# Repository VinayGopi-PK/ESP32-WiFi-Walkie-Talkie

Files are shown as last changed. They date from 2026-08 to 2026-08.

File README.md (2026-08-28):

# ESP32 Wi-Fi Walkie-Talkie

An **ESP32-based real-time Wi-Fi Walkie-Talkie** designed for voice communication using **UDP audio streaming**. The system uses an **INMP441 I2S digital microphone**, **MAX98357A I2S audio amplifier**, and a **Push-to-Talk (PTT)** control.

The hardware was designed in **KiCad**, including the schematic, PCB layout, and 3D visualization. The repository also contains the ESP32 Arduino source code and Gerber files for PCB manufacturing.

---

## Project Overview

This project is a wireless voice communication system based on two ESP32 boards communicating over Wi-Fi.

The voice signal is captured by the **INMP441 digital microphone** through the I2S interface. The ESP32 processes and transmits the audio data using **UDP over Wi-Fi**. At the receiving side, the audio is sent through I2S to the **MAX98357A audio amplifier**, which drives the speaker.

A **Push-to-Talk (PTT)** button is used to control voice transmission.

### Audio Communication Path

```text
Voice
  ↓
INMP441 I2S Microphone
  ↓
ESP32
  ↓
UDP Audio Streaming over Wi-Fi
  ↓
ESP32
  ↓
MAX98357A I2S Audio Amplifier
  ↓
Speaker
```

---

## Main Features

* ESP32-based wireless communication
* Real-time UDP audio streaming
* Wi-Fi-based voice communication
* I2S digital audio interface
* INMP441 I2S digital microphone
* MAX98357A I2S audio amplifier
* Push-to-Talk (PTT) control
* Custom PCB designed using KiCad
* Complete schematic design
* PCB layout design
* Front and back PCB layout
* 3D PCB visualization
* Gerber files for PCB manufacturing

---

## Hardware

| Component | Function |
| --- | --- |
| ESP32 | Main microcontroller and Wi-Fi communication |
| INMP441 | I2S digital microphone |
| MAX98357A | I2S audio amplifier |
| Push-to-Talk Button | Controls voice transmission |
| Speaker | Audio output |
| Custom PCB | Integrates the system hardware |

---

## Software

The ESP32 firmware was developed using **Arduino IDE**.

The repository contains the final Arduino source code used for the ESP32 Walkie-Talkie system.

### Communication

* Wireless technology: **Wi-Fi**
* Communication protocol: **UDP**
* Audio interface: **I2S**

---

## PCB Design

The custom PCB was designed using **KiCad**.

The PCB design includes:

* Complete schematic
* Component placement
* PCB routing
* Front copper layout
* Back copper layout
* Power and signal routing
* 3D PCB visualization
* Gerber manufacturing files

---

## PCB Design Preview

### Schematic

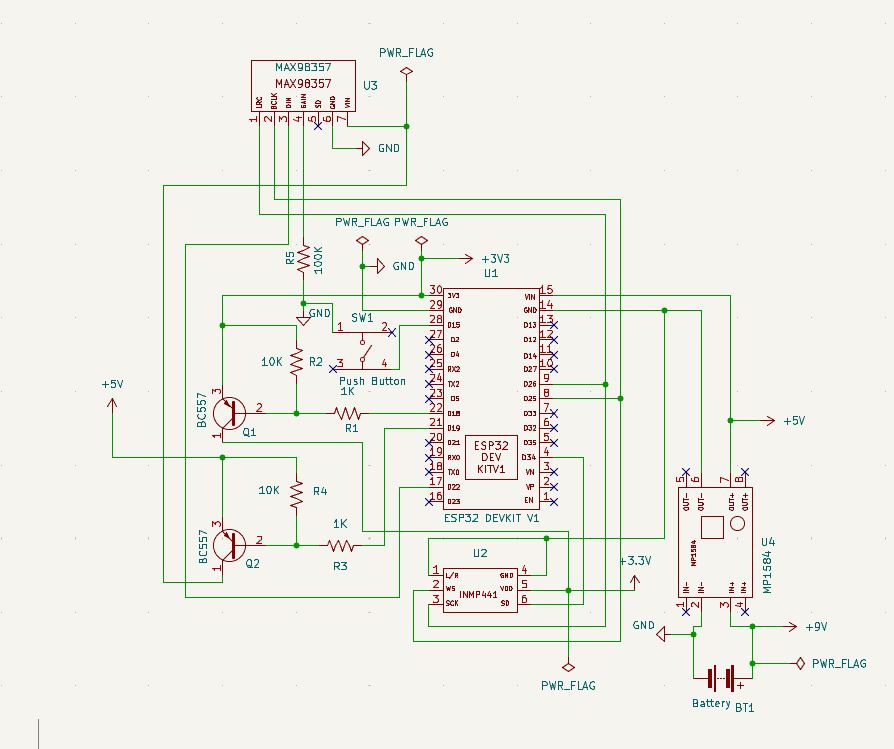
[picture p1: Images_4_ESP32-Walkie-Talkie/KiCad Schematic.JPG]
ESP32 Wi-Fi Walkie-Talkie Schematic


### PCB Front Layout

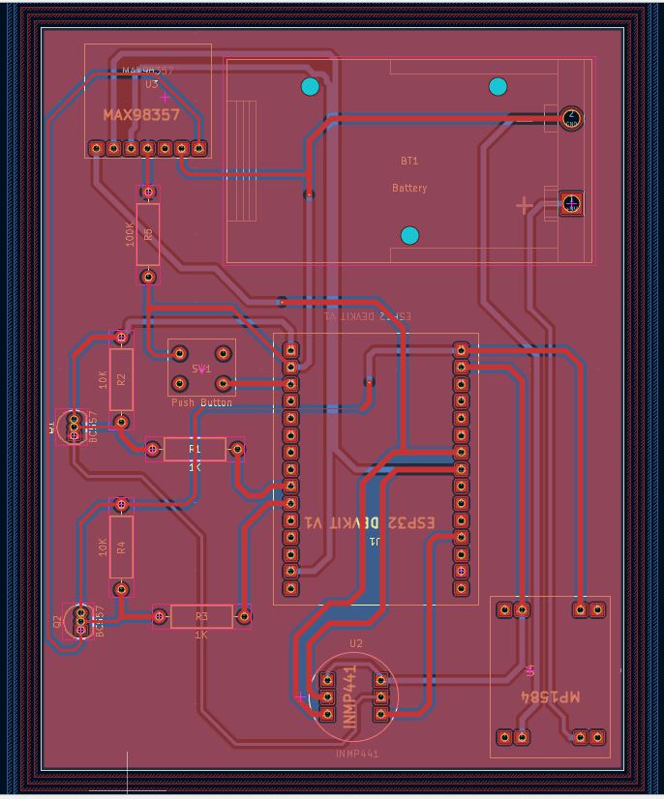
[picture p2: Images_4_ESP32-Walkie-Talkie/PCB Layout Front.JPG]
PCB Front Layout


### PCB Back Layout

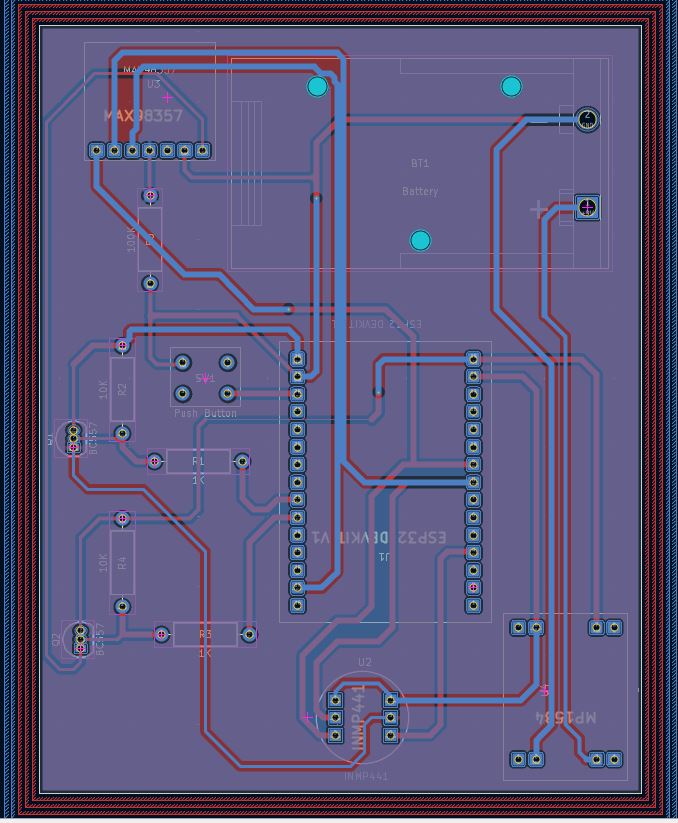
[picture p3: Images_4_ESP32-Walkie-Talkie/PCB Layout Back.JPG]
PCB Back Layout


### 3D View

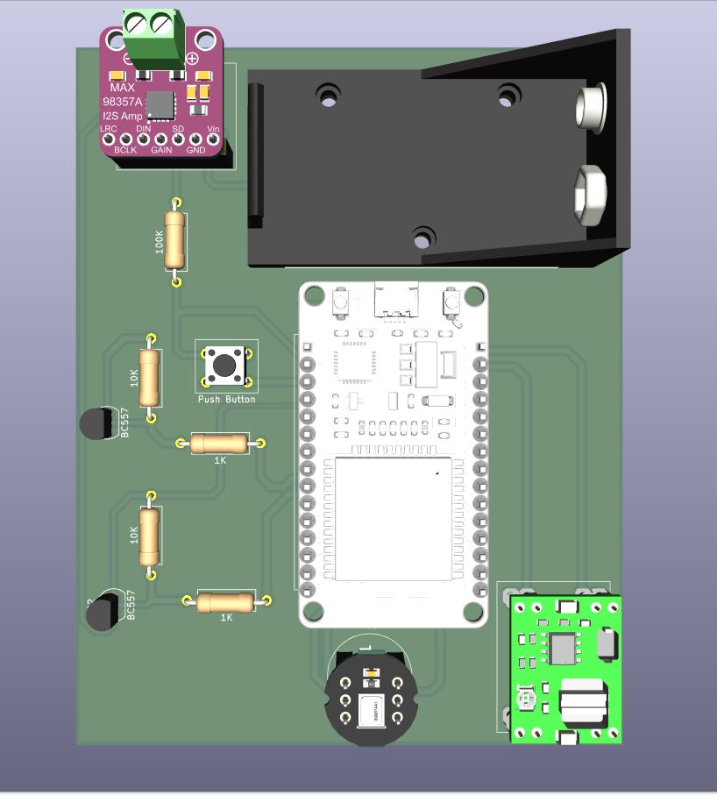
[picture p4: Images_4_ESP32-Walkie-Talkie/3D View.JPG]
PCB 3D View


---

## Repository Contents

### KiCad Design Files

The `ESP32_Walkie-Talkie Files` folder contains the KiCad project files, including:

* KiCad project file
* KiCad schematic
* KiCad PCB layout
* Component/project data files

### Arduino Source Code

The `Final_Codes` folder contains the final ESP32 Arduino source code for the Walkie-Talkie system.

### Gerber Files

The `Gerber Files_4_ESP32 Walkie-Talkie` folder contains the generated Gerber files required for PCB manufacturing.

### Project Images

The `Images_4_ESP32-Walkie-Talkie` folder contains:

* Schematic image
* PCB front layout
* PCB back layout
* PCB 3D view

---

## Design Tools

* **KiCad** — Schematic and PCB design
* **Arduino IDE** — ESP32 firmware development

---

## Technical Highlights

**Microcontroller:** ESP32
**Wireless Communication:** Wi-Fi
**Communication Protocol:** UDP
**Audio Interface:** I2S
**Digital Microphone:** INMP441
**Audio Amplifier:** MAX98357A
**Control:** Push-to-Talk (PTT)

---

## Project Objective

The objective of this project was to develop an **ESP32-based wireless voice communication system** while combining embedded programming, Wi-Fi networking, real-time UDP audio streaming, digital I2S audio, schematic design, PCB layout, and PCB manufacturing file generation.

---

## Project Type

**ESP32 Embedded System | Wi-Fi Communication | Digital Audio | PCB Design**

**Design Software:** KiCad
**Programming Environment:** Arduino IDE

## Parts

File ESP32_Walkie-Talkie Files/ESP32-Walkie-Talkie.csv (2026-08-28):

Reference | Qty | Value | DNP | Exclude from BOM | Exclude from Board | Footprint | Datasheet
BT1 | 1 | Battery |  |  |  | Battery:BatteryHolder_Eagle_12BH611-GR
Q1,Q2 | 2 | BC557 |  |  |  | Package_TO_SOT_THT:TO-92_Inline | https://www.onsemi.com/pub/Collateral/BC556BTA-D.pdf
R1,R3 | 2 | 1K |  |  |  | Resistor_THT:R_Axial_DIN0309_L9.0mm_D3.2mm_P12.70mm_Horizontal
R2,R4 | 2 | 10K |  |  |  | Resistor_THT:R_Axial_DIN0309_L9.0mm_D3.2mm_P12.70mm_Horizontal
R5 | 1 | 100K |  |  |  | Resistor_THT:R_Axial_DIN0309_L9.0mm_D3.2mm_P12.70mm_Horizontal
SW1 | 1 | Push Button |  |  |  | Footprint_Button_Tactile_6x6mm:Footprint_Button_Tactile_6x6mm
U1 | 1 | ESP32 DEVKIT V1 |  |  |  | Footprint_ESP32_DevKitV1_30Pin:ESP32_DevKit_30Pin_Socket
U2 | 1 | INMP441 |  |  |  | Footprint_INMP441:INMP441
U3 | 1 | MAX98357 |  |  |  | Footprint_MAX98357:MAX98357
U4 | 1 | MP1584 |  |  |  | Footprint_MP1584:MP1584

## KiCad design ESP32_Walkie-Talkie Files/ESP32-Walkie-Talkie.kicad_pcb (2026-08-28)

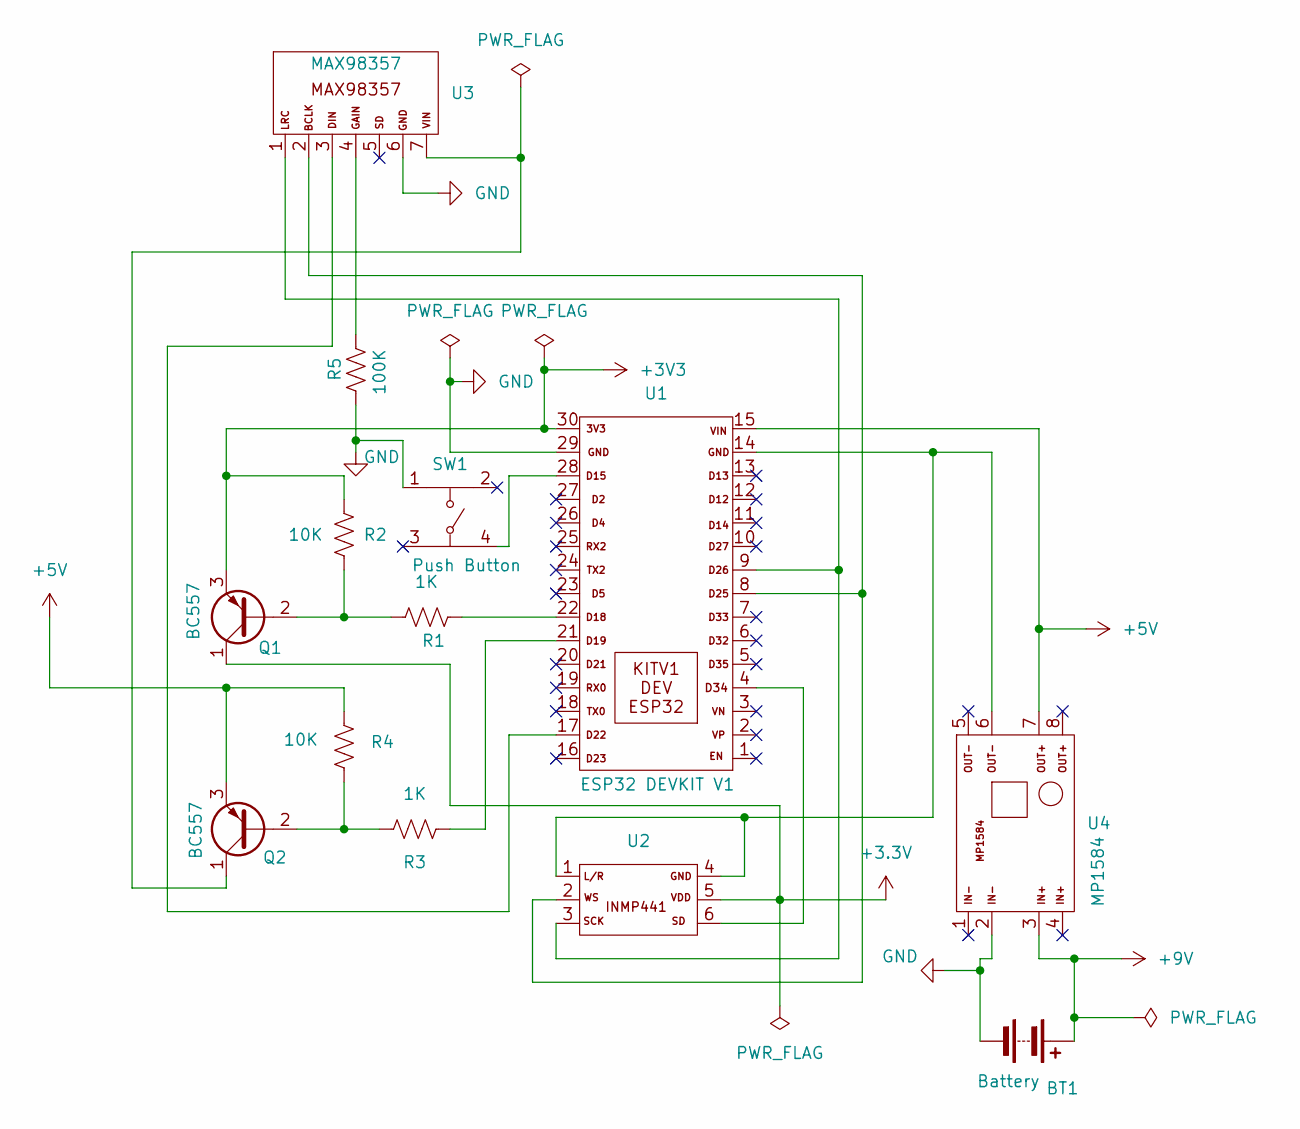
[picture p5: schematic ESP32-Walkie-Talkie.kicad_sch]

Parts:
BT1: Battery; BatteryHolder_Eagle_12BH611-GR
Q1, Q2: BC557; TO-92_Inline
R1, R3: 1K; R_Axial_DIN0309_L9.0mm_D3.2mm_P12.70mm_Horizontal
R2, R4: 10K; R_Axial_DIN0309_L9.0mm_D3.2mm_P12.70mm_Horizontal
R5: 100K; R_Axial_DIN0309_L9.0mm_D3.2mm_P12.70mm_Horizontal
SW1: Push Button; Footprint_Button_Tactile_6x6mm
U1: ESP32 DEVKIT V1; ESP32_DevKit_30Pin_Socket
U2: INMP441
U3: MAX98357
U4: MP1584

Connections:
+3.3V: Q1.1 (C), U2.5 (VDD)
+3V3: Q1.3 (E), R2.1, U1.30 (3V3)
+5V: Q2.3 (E), R4.1, U1.15 (VIN), U4.7 (OUT+)
+9V: BT1.1 (+), U4.3 (IN+)
GND: BT1.2 (-), R5.2, SW1.1, U1.29 (GND), U3.6 (GND), U4.2 (IN-)
unnamed: Q1.2 (B), R1.1, R2.2
unnamed: Q2.2 (B), R3.1, R4.2
unnamed: Q2.1 (C), U3.7 (VIN)
unnamed: SW1.4, U1.28 (D15)
unnamed: R1.2, U1.22 (D18)
unnamed: R3.2, U1.21 (D19)
unnamed: U1.17 (D22), U3.3 (DIN)
unnamed: U1.8 (D25), U2.2 (WS), U3.2 (BCLK)
unnamed: U1.9 (D26), U2.3 (SCK), U3.1 (LRC)
unnamed: U1.4 (D34), U2.6 (SD)
unnamed: U1.14 (GND), U2.1 (L/R), U2.4 (GND), U4.6 (OUT-)
unnamed: R5.1, U3.4 (GAIN)

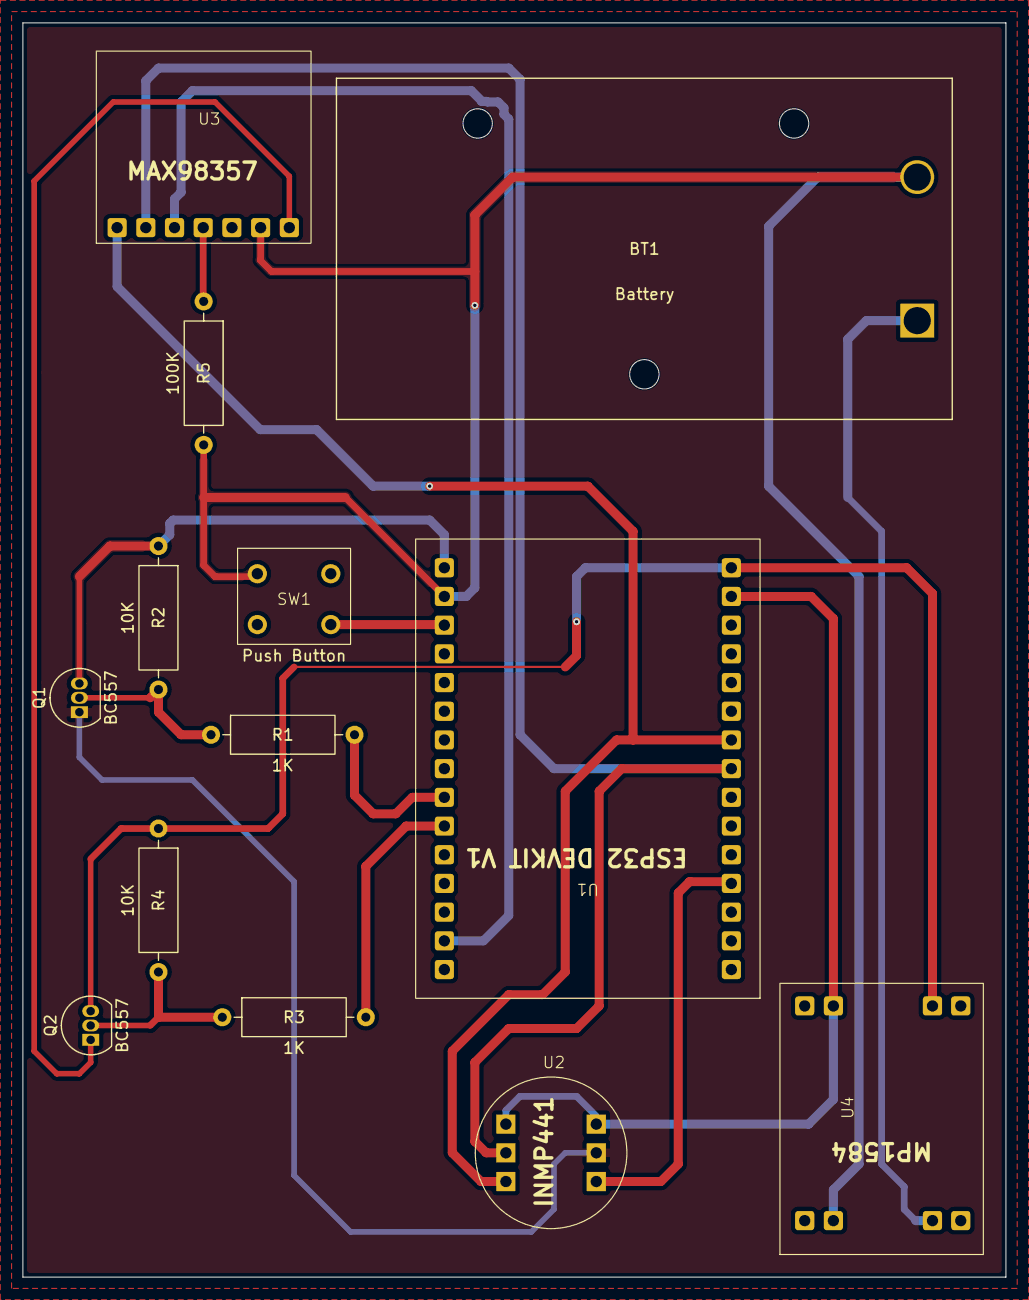
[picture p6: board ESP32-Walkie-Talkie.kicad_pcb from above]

Board: 2 copper layers, 87.0 x 111.0 mm, 13 parts (0 on the bottom side), 17 nets.

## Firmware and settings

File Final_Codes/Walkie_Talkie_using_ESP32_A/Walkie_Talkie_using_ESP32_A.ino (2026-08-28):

#include <WiFi.h>
#include <WiFiUdp.h>
#include <driver/i2s.h>

const char* ssid = "USERNAME"; //Your WiFi Username
const char* password = "Password"; // Your WiFi Password

// ===== CHANGE THIS PER DVICE =======
IPAddress local_IP(192,168,29,200);   // Set unique IP for this device
IPAddress peerIP(192,168,29,201);    //  Set IP for other device 
IPAddress gateway(192,168,29,1);
IPAddress subnet(255,255,255,0);
const int port = 1234;
WiFiUDP udp;

// I2S Settings 
#define I2S_NUM I2S_NUM_0
#define I2S_SAMPLE_RATE 32000
#define I2S_BITS_PER_SAMPLE I2S_BITS_PER_SAMPLE_32BIT
#define I2S_READ_LEN 2048
#define I2S_DMA_BUF_LEN 1024

#define I2S_BCLK_PIN 26
#define I2S_WS_PIN 25
#define I2S_DIN_PIN 22 // To DAC
#define I2S_DOUT_PIN 34 // From Mic

#define LED_PIN 2
#define PTT_PIN 15

#define MIC_POWER_PIN 18  // Controls INMP441 VDD
#define DAC_POWER_PIN 19 //  Controls MAX98357A VDD

const float volumeBoost = 5.0;
int32_t i2sBuffer[I2S_READ_LEN / 4];
int32_t amplifiedBuffer[I2S_READ_LEN / 4];

bool i2sInstalled = false;
bool isTransmitMode = false;

void setupI2S_RX(){
  if(i2sInstalled){
    i2s_driver_uninstall(I2S_NUM);
    i2sInstalled = false;
  }

  i2s_config_t config = {
    .mode = (i2s_mode_t)(I2S_MODE_MASTER | I2S_MODE_RX),
    .sample_rate = I2S_SAMPLE_RATE,
    .bits_per_sample = I2S_BITS_PER_SAMPLE,
    .channel_format = I2S_CHANNEL_FMT_ONLY_LEFT,
    .communication_format = I2S_COMM_FORMAT_I2S,
    .intr_alloc_flags = ESP_INTR_FLAG_LEVEL1,
    .dma_buf_count = 8,
    .dma_buf_len = I2S_DMA_BUF_LEN,
    .use_apll = false,
    .tx_desc_auto_clear = false,
    .fixed_mclk = 0
  };

  i2s_pin_config_t pins = {
    .bck_io_num = I2S_BCLK_PIN,
    .ws_io_num = I2S_WS_PIN,
    .data_out_num = I2S_PIN_NO_CHANGE,
    .data_in_num = I2S_DOUT_PIN
  };

  i2s_driver_install(I2S_NUM, &config, 0, NULL);
  i2s_set_pin(I2S_NUM, &pins);
  i2s_zero_dma_buffer(I2S_NUM);
  i2sInstalled = true;
}


void setupI2S_TX(){
   if(i2sInstalled){
    i2s_driver_uninstall(I2S_NUM);
    i2sInstalled = false;
   }

  i2s_config_t config = {
    .mode = (i2s_mode_t)(I2S_MODE_MASTER | I2S_MODE_TX),
    .sample_rate = I2S_SAMPLE_RATE,
    .bits_per_sample = I2S_BITS_PER_SAMPLE,
    .channel_format = I2S_CHANNEL_FMT_ONLY_LEFT,
    .communication_format = I2S_COMM_FORMAT_I2S,
    .intr_alloc_flags = ESP_INTR_FLAG_LEVEL1,
    .dma_buf_count = 8,
    .dma_buf_len = I2S_DMA_BUF_LEN,
    .use_apll = false,
    .tx_desc_auto_clear = true,
    .fixed_mclk = 0
  };

  i2s_pin_config_t pins = {
    .bck_io_num = I2S_BCLK_PIN,
    .ws_io_num = I2S_WS_PIN,
    .data_out_num = I2S_DIN_PIN,
    .data_in_num = I2S_PIN_NO_CHANGE
  };

  i2s_driver_install(I2S_NUM, &config, 0, NULL);
  i2s_set_pin(I2S_NUM, &pins);
  i2s_zero_dma_buffer(I2S_NUM);
  i2sInstalled = true;
}

void connectWiFi(){
  WiFi.config(local_IP,gateway,subnet);
  WiFi.begin(ssid,password);
  Serial.print("Connecting to Wi-Fi");
   while(WiFi.status() != WL_CONNECTED){
    delay(500);
    Serial.print(".");
  }
  Serial.println("\nConnected! IP: ");
  Serial.println(WiFi.localIP());
}


void setup(){
  Serial.begin(115200);
  pinMode(LED_PIN, OUTPUT);
  pinMode(PTT_PIN, INPUT_PULLUP);  //Active LOW
  pinMode(MIC_POWER_PIN, OUTPUT);  // Controls INMP441 VDD
  pinMode(DAC_POWER_PIN, OUTPUT);  // Controls MAX98357A VDD
  connectWiFi();
  udp.begin(port);
}

void loop(){
  bool pttPressed = digitalRead(PTT_PIN) == LOW;

  if(pttPressed){
    // ==== Transmit Mode ====
    if(!isTransmitMode){
      setupI2S_RX();
      isTransmitMode = true;
      digitalWrite(MIC_POWER_PIN, HIGH);  // Enable MIC
      digitalWrite(DAC_POWER_PIN, LOW);  //  Disable DAC
    }

   size_t bytesRead = 0;
   esp_err_t result = i2s_read(I2S_NUM, (void*)i2sBuffer, sizeof(i2sBuffer), &bytesRead, 10 / portTICK_PERIOD_MS);

   if(result == ESP_OK && bytesRead > 0){
    udp.beginPacket(peerIP,port);
    udp.write((uint8_t*)i2sBuffer,bytesRead);
    udp.endPacket();
    digitalWrite(LED_PIN, HIGH);
   }
  } else {
   // ==== Receive Mode ====
   if(isTransmitMode){
    setupI2S_TX();
    isTransmitMode = false;
    digitalWrite(MIC_POWER_PIN, LOW);  // Enable DAC
    digitalWrite(DAC_POWER_PIN, HIGH);  //  Disable MIC
   }

   int packetSize = udp.parsePacket();
   if(packetSize > 0 && packetSize <= sizeof(i2sBuffer)){
    udp.read((uint8_t*)i2sBuffer, packetSize);
    int sampleCount = packetSize / sizeof(int32_t);

    for(int i = 0; i < sampleCount; i++){
      int32_t amplified = i2sBuffer[i] * volumeBoost;
      if(amplified > INT32_MAX) amplified = INT32_MAX;
      else if(amplified < INT32_MIN) amplified = INT32_MIN;
      amplifiedBuffer[i] = (int32_t)amplified;
    }

    size_t written;
    i2s_write(I2S_NUM, amplifiedBuffer, sampleCount * sizeof(int32_t), &written, 10 / portTICK_PERIOD_MS);
    digitalWrite(LED_PIN, HIGH);
    }else{
    digitalWrite(LED_PIN, LOW);
  }
  }
}

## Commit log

2026-08-27 Create KiCad
2026-08-27 Create Arduino
2026-08-28 Revise README for ESP32 Wi-Fi Walkie-Talkie project
    Updated README to enhance project overview and details.
